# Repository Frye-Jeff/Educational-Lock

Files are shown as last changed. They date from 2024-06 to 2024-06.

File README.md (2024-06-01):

# Educational Lock

I designed a 3D printable demonstration lock for Philly TOOOL or anyone who wants one. 

v1: Contains the STL files I used to print my initial proof of concept. 

v2: Is a slightly improved version. Part count is reduced for easier assembly. An attempt was made to make the design parametric. I have included the Fusion files along with STLs.

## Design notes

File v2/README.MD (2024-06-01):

# V2 Educational Lock Notes

To assemble this model, you must print five parts and a spring. I used a 10mm by 30mm spring with a thickness of 0.5mm. You don't want the spring to be too stiff or the lock will be difficult to demo.

I recommend using four colors of filament.

Color 1: 

	Lock Body

Color 2:

	Lock Core
	Lock Clip

Color 3:

	Top Pin
	Spool Pin (Alternative to the normal Top Pin)

Color 4:

	Bottom Pin

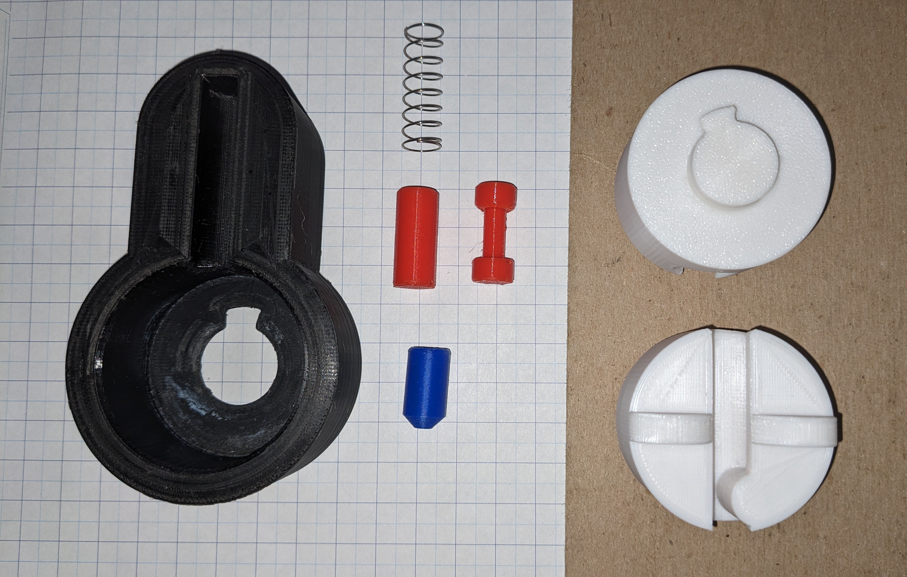
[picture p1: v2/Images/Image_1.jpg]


Construction:

Use the lock body to center the lock clip to the lock core and glue the clip to the core. With the core in the locked position, I recommend the clip's tab be in the 5 o'clock position. The clip/ring prevents the lock from accidentally coming apart during use.

Assembly:
1. Insert the Bottom pin into the lock core.
2. Insert the spring into the top of the lock body.
3. Insert the Top Pin (or Spool Pin) into the top of the Lock Body. Compressing the spring so you can insert the Lock Core into the Lock body.
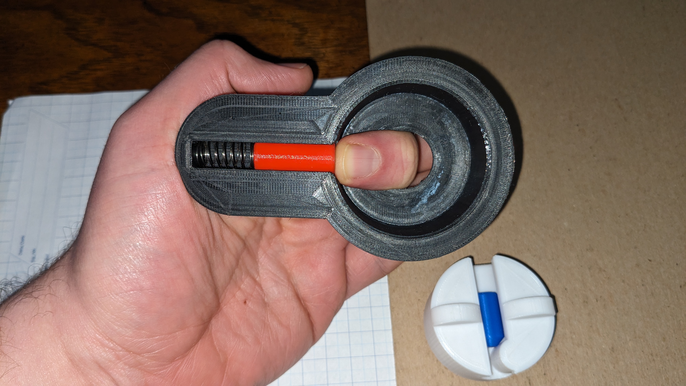
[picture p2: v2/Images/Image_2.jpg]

4. Twist the Lock Core until the Clip aligns with the gap in the Lock Ring and fully seat the core.
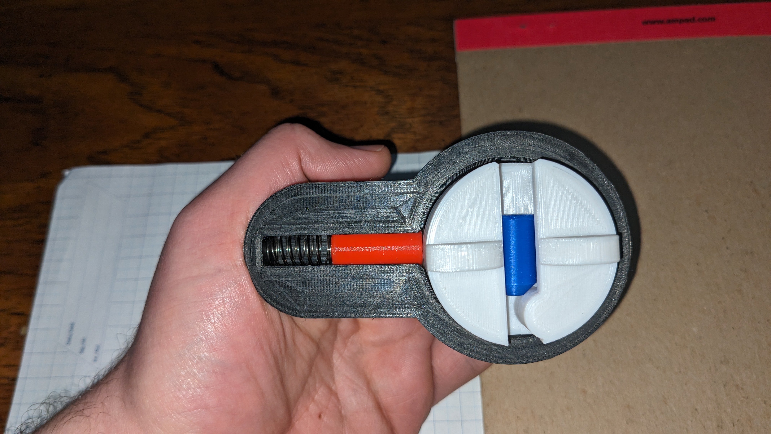
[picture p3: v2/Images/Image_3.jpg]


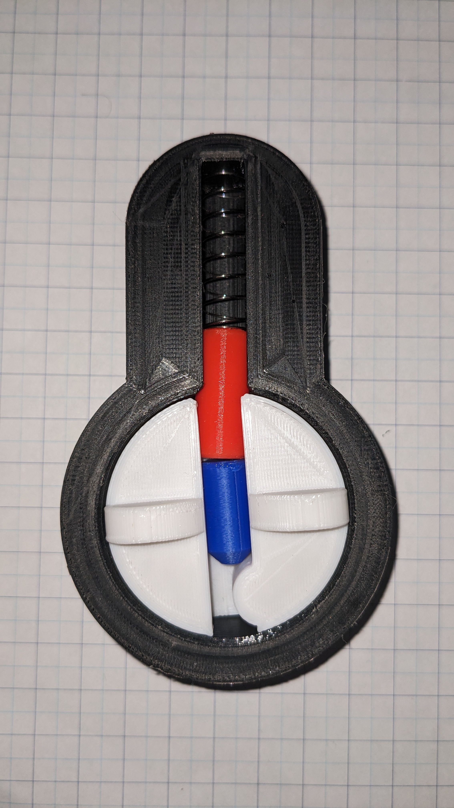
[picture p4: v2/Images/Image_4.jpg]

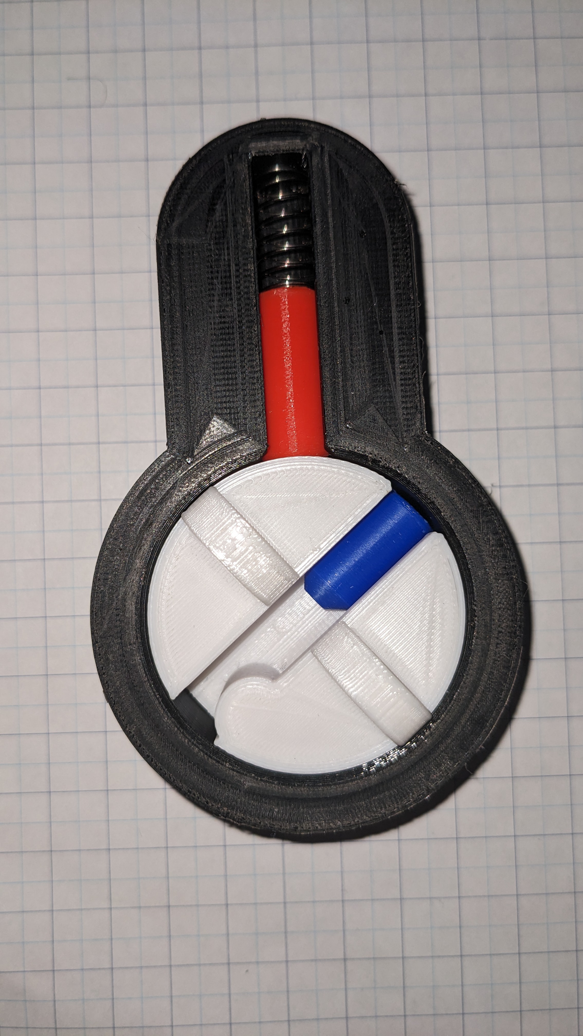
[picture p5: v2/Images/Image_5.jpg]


 <p xmlns:cc="http://creativecommons.org/ns#" >This work is licensed under <a href="https://creativecommons.org/licenses/by-nc-sa/4.0/?ref=chooser-v1" target="_blank" rel="license noopener noreferrer" style="display:inline-block;">Creative Commons Attribution-NonCommercial-ShareAlike 4.0 International</a></p>

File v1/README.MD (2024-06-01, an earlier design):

# V1 Educational Lock Notes

To assemble this model, you will need to print six parts and a spring. I used a 3/8-inch by 1 1/4-inch spring from my local hardware store.

I recommend using four colors of filament.

Color 1: 

	Lock Body
	Lock Ring

Color 2:

	Lock Core
	Lock Clip

Color 3:

	Top Pin
	Spool Pin (Alternative to the normal Top Pin)

Color 4:

	Bottom Pin

Construction:
Press the Lock Ring into the Lock body with the slopped edge to the back of the lock and the notch at the 12 o'clock position. Use a small amount of super glue on the inside of the lock to affix the ring to the body. 

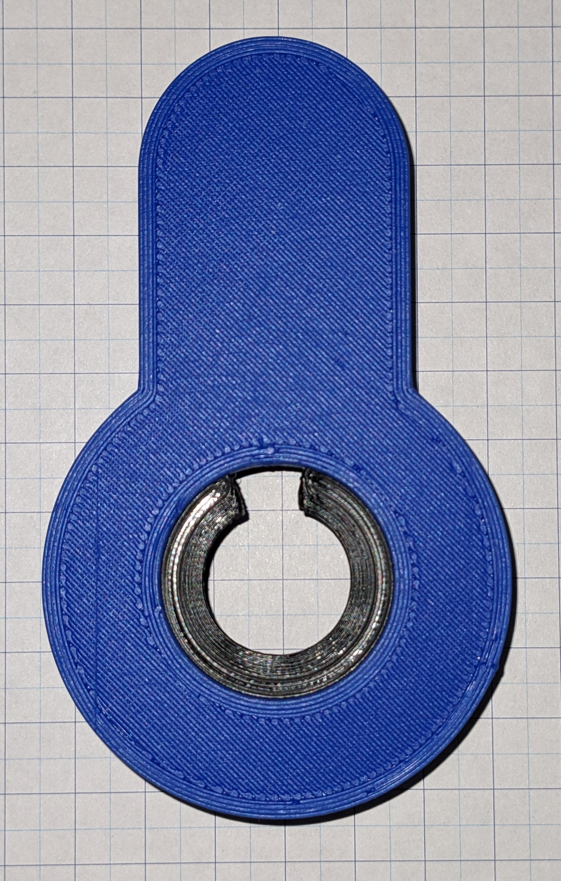
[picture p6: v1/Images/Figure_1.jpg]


Use the lock body to center the lock clip to the lock core and glue the clip to the core. With the core in the locked position, I recommend the clip's tab be in the 5 o'clock position. The clip/ring prevents the lock from accidentally coming apart during use.

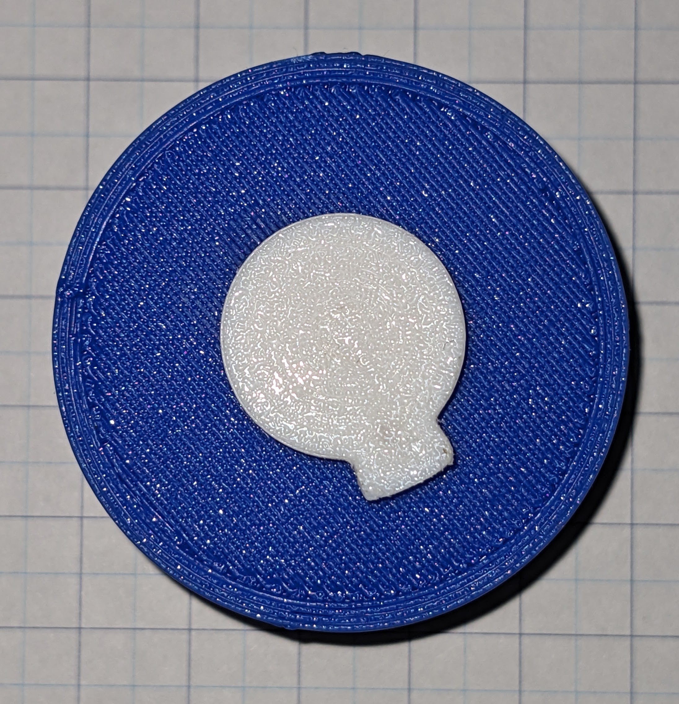
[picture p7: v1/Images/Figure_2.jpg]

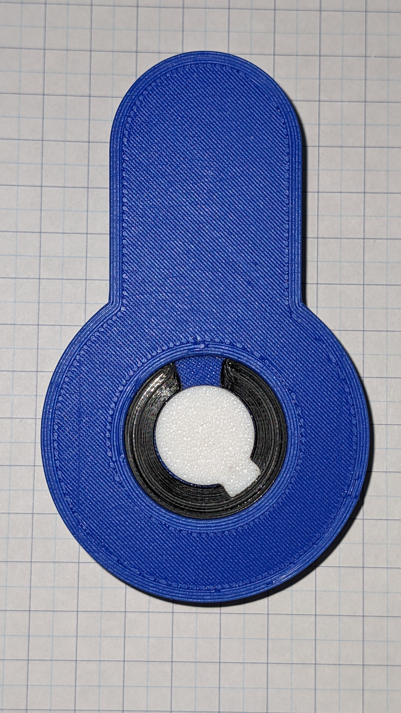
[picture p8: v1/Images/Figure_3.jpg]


Assembly:
1. Insert the Bottom pin into the lock core.
2. Insert the spring into the top of the lock body.
3. Insert the Top Pin (or Spool Pin) into the top of the Lock Body. Compressing the spring so you can insert the Lock Core into the Lock body.
4. Twist the Lock Core until the Clip aligns with the gap in the Lock Ring and fully seat the core.

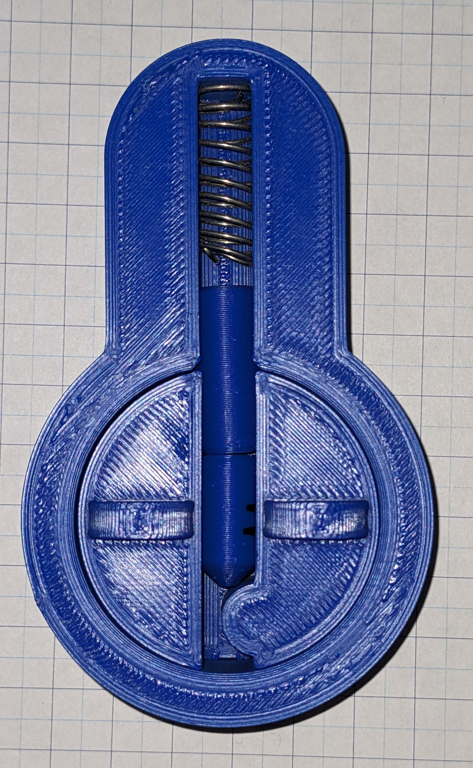
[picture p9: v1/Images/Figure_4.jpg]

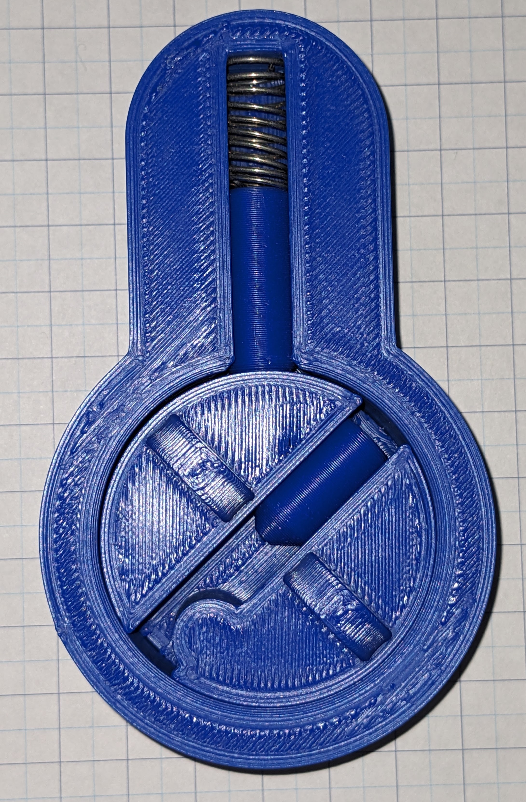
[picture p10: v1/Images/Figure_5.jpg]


 <p xmlns:cc="http://creativecommons.org/ns#" >This work is licensed under <a href="https://creativecommons.org/licenses/by-nc-sa/4.0/?ref=chooser-v1" target="_blank" rel="license noopener noreferrer" style="display:inline-block;">Creative Commons Attribution-NonCommercial-ShareAlike 4.0 International</a></p>

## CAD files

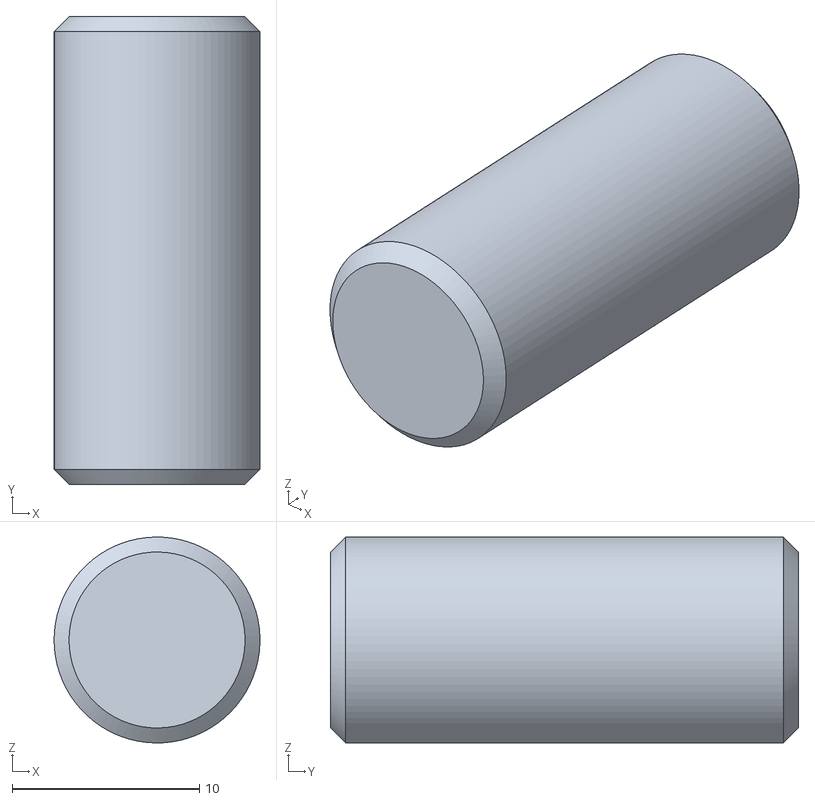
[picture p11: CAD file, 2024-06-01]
v2/STL/TopPin_v2.stl
11.0 x 25.0 x 11.0

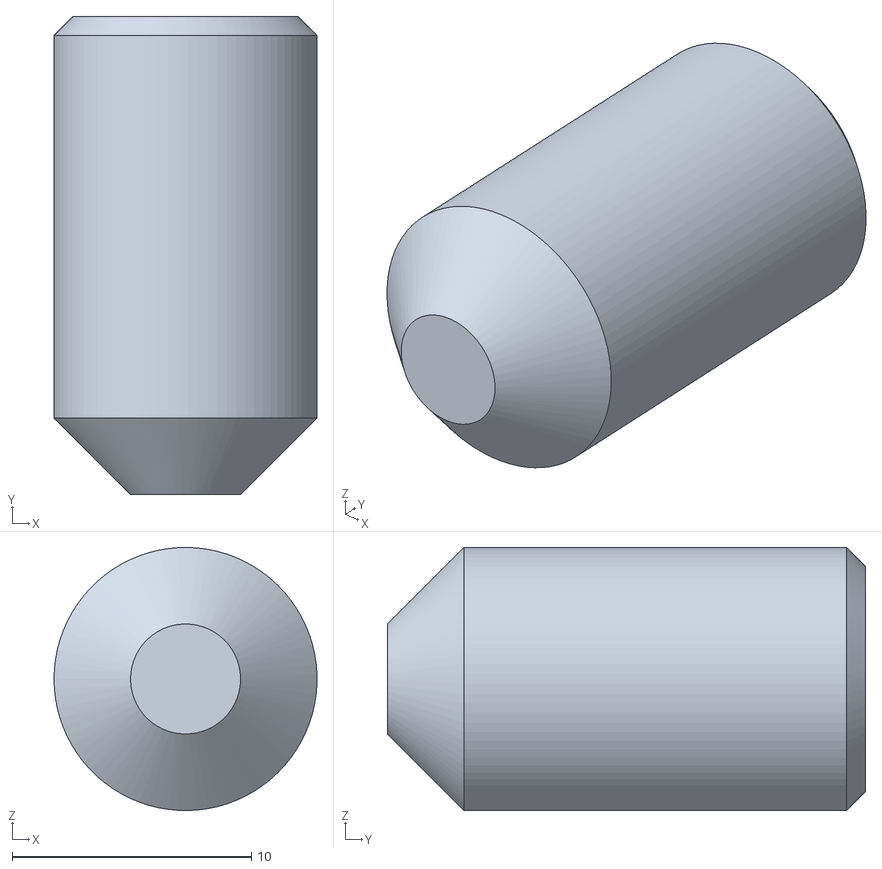
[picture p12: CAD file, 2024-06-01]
v2/STL/BottomPin_v2.stl
11.0 x 20.0 x 11.0

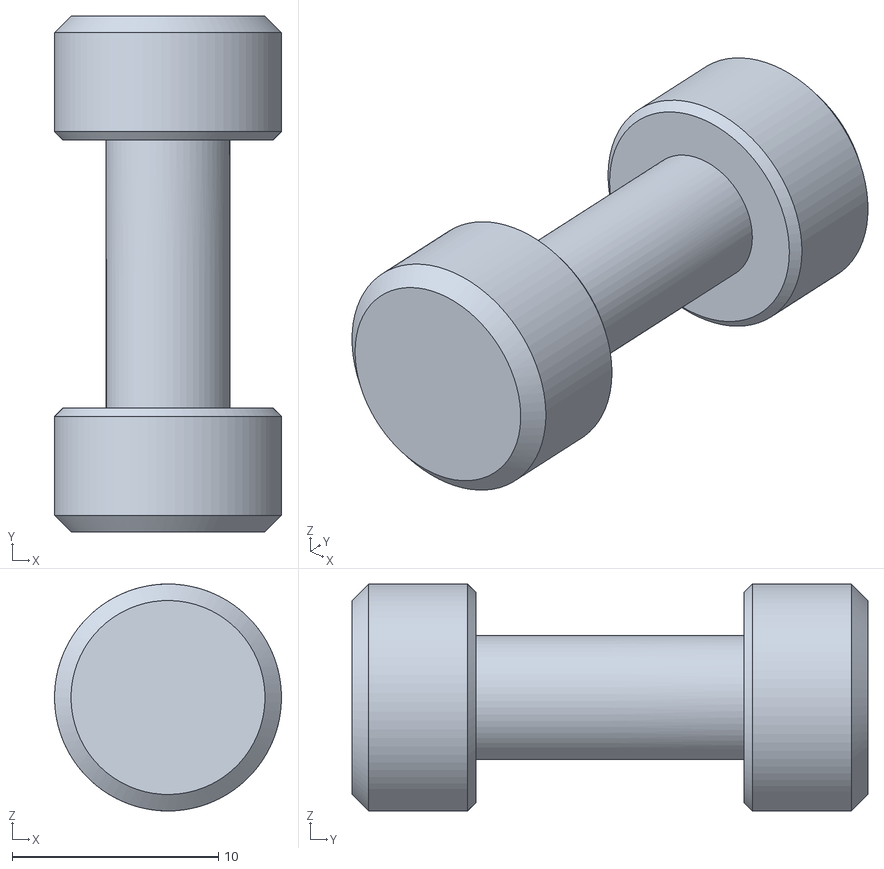
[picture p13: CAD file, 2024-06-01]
v2/STL/SpoolPin_v2.stl
11.0 x 25.0 x 11.0

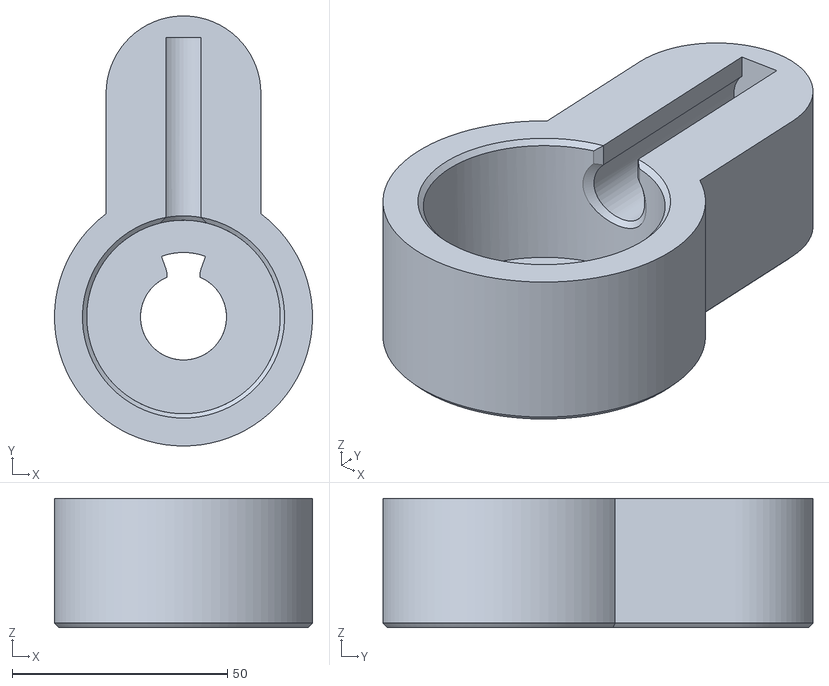
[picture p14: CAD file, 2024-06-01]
v2/STL/Lock_Body_v2.stl
60.0 x 100.0 x 30.0

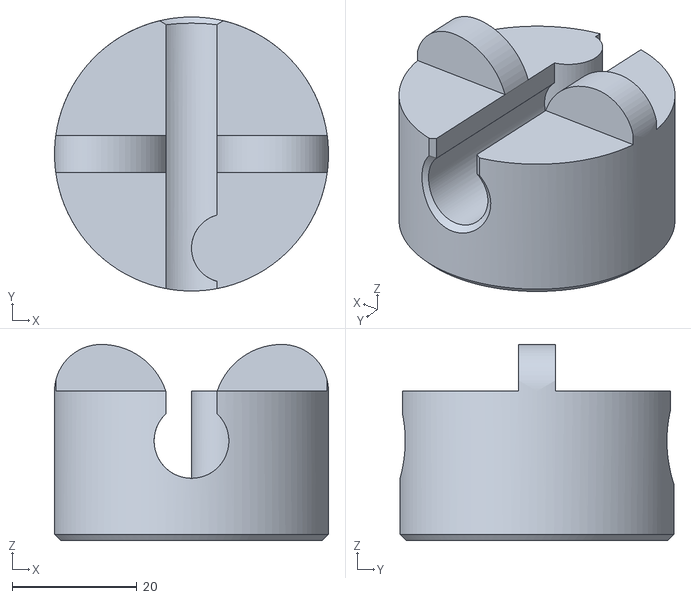
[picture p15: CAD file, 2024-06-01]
v2/STL/CoreWithTabs_v2.stl
44.0 x 44.0 x 31.5

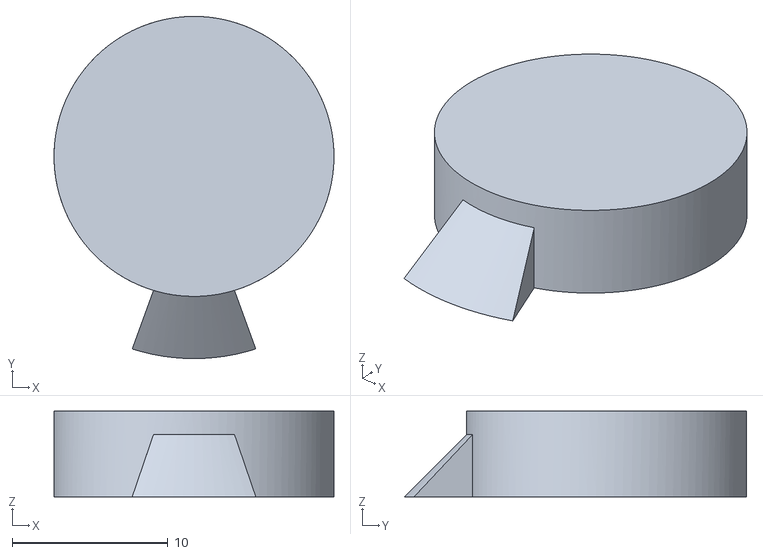
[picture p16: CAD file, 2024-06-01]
v2/STL/Catch_v2.stl
18.0 x 22.0 x 5.50

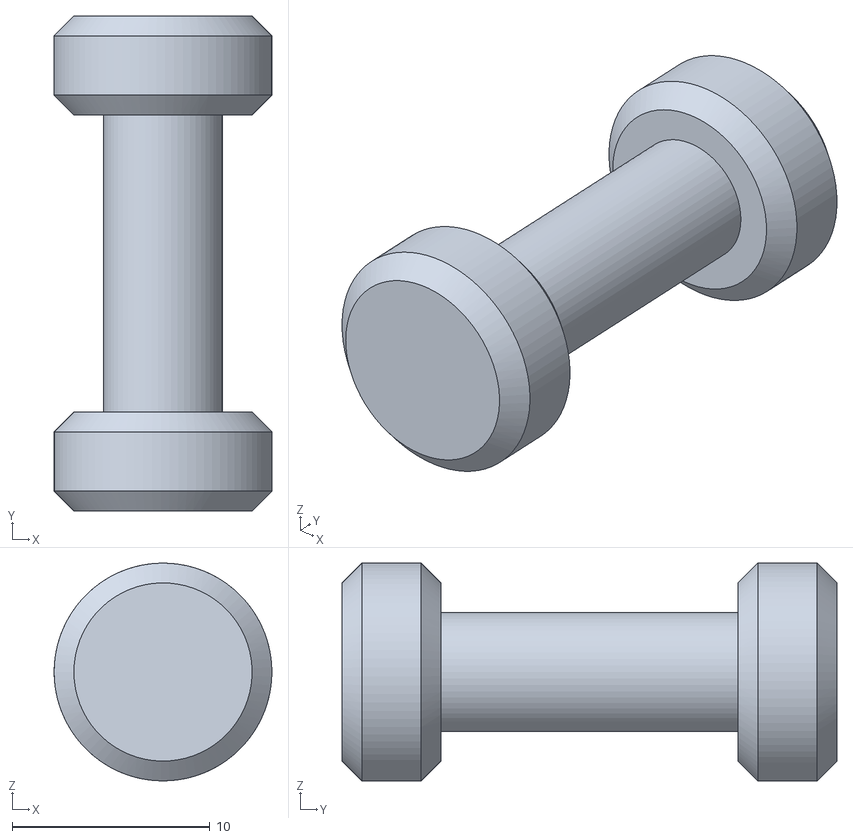
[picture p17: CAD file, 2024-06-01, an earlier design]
v1/STL/SpoolPin_v1.stl
11.0 x 25.0 x 11.0

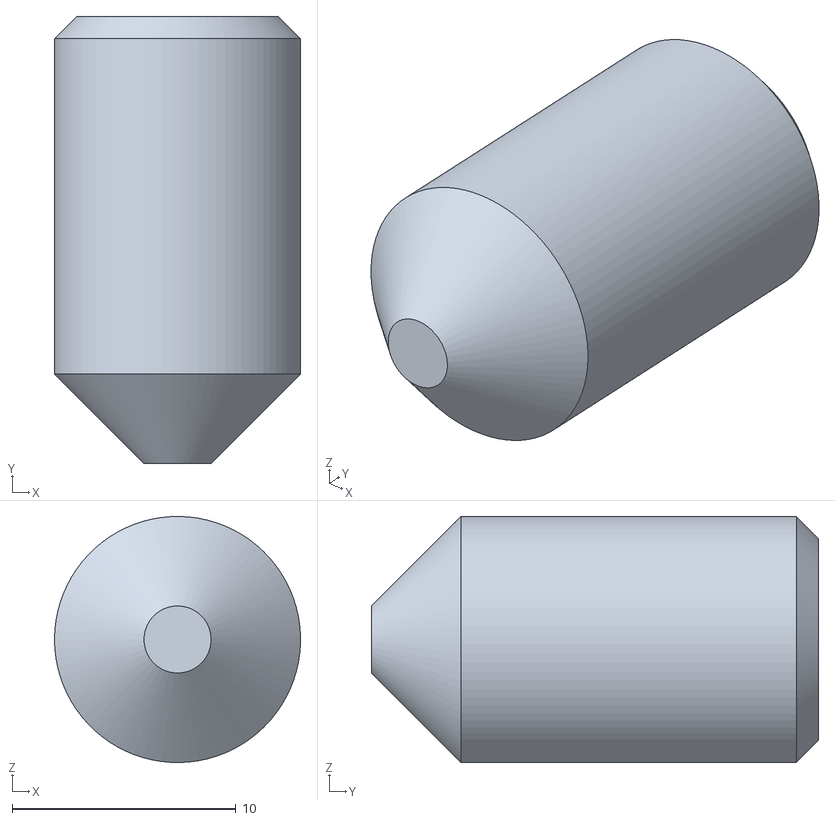
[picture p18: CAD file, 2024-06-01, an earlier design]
v1/STL/DriverPin_v1.stl
11.0 x 20.0 x 11.0

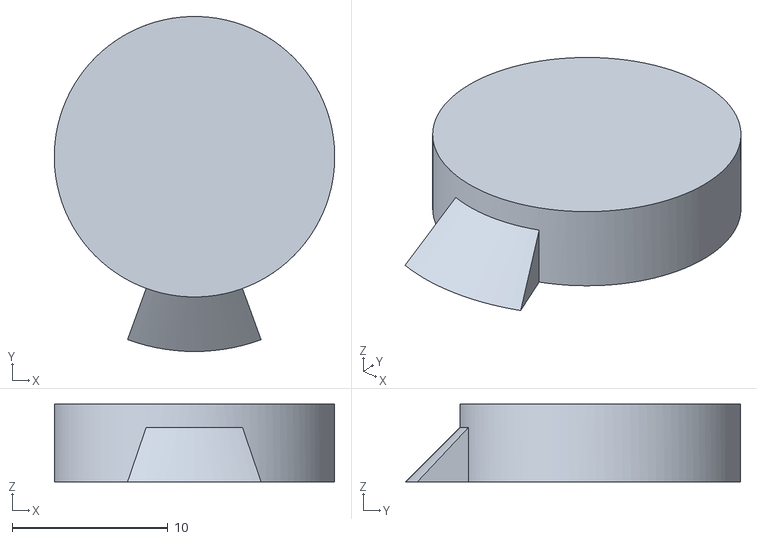
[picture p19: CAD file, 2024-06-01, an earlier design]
v1/STL/LockClip_v1.stl
18.0 x 21.5 x 5.00

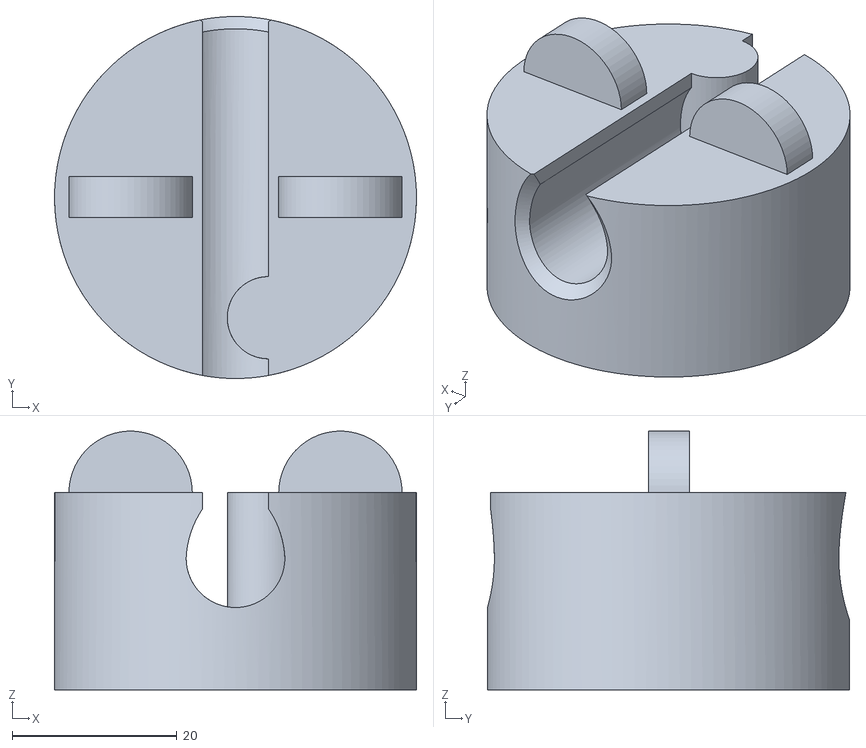
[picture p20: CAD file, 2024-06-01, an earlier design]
v1/STL/Core_v1.stl
44.0 x 44.0 x 31.4

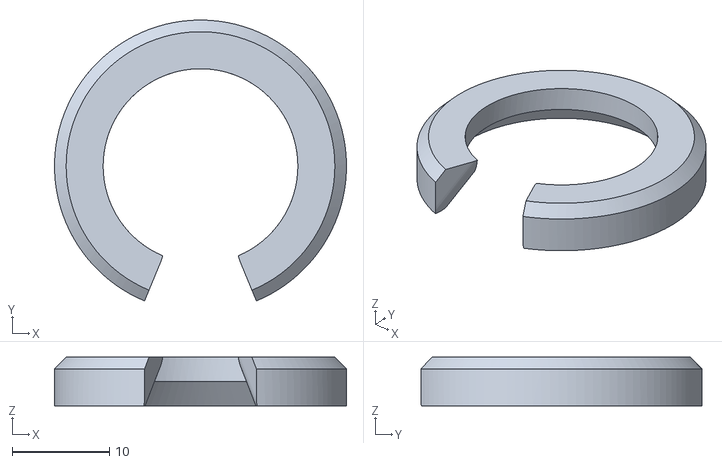
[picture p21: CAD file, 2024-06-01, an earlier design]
v1/STL/LockRing_v1.stl
30.0 x 28.9 x 5.00

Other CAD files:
v1/STL/LockBody_v1.stl
v1/STL/TopPin_v1.stl
v2/f3d/BottomPin_v2.f3d
v2/f3d/Catch_v2.f3d
v2/f3d/CoreWithTabs_v2.f3d
v2/f3d/Educational_Lock_Parametric_v2.f3d
v2/f3d/Lock Body_v2.f3d
v2/f3d/SpoolPin_v2.f3d
v2/f3d/TopPin_v2.f3d
